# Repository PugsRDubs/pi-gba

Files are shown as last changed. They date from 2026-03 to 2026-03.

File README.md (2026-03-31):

# pi-gba
A simple, easy to assemble, DIY retro gaming handheld.

The pi-gba was designed to be pretty easy to build. Order the pcb, parts, and 3d print the case, and assembly is straightforward. The pi, battery board, and usbc breakout are placed on top of and soldered directly to the main board.

### images
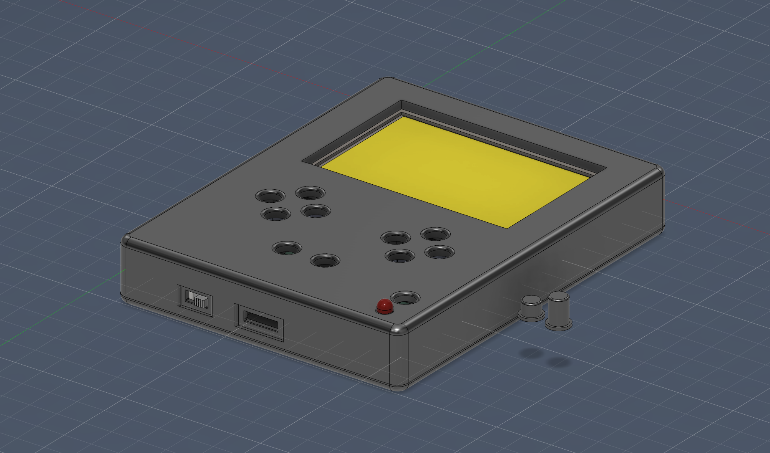
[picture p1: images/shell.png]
Shell

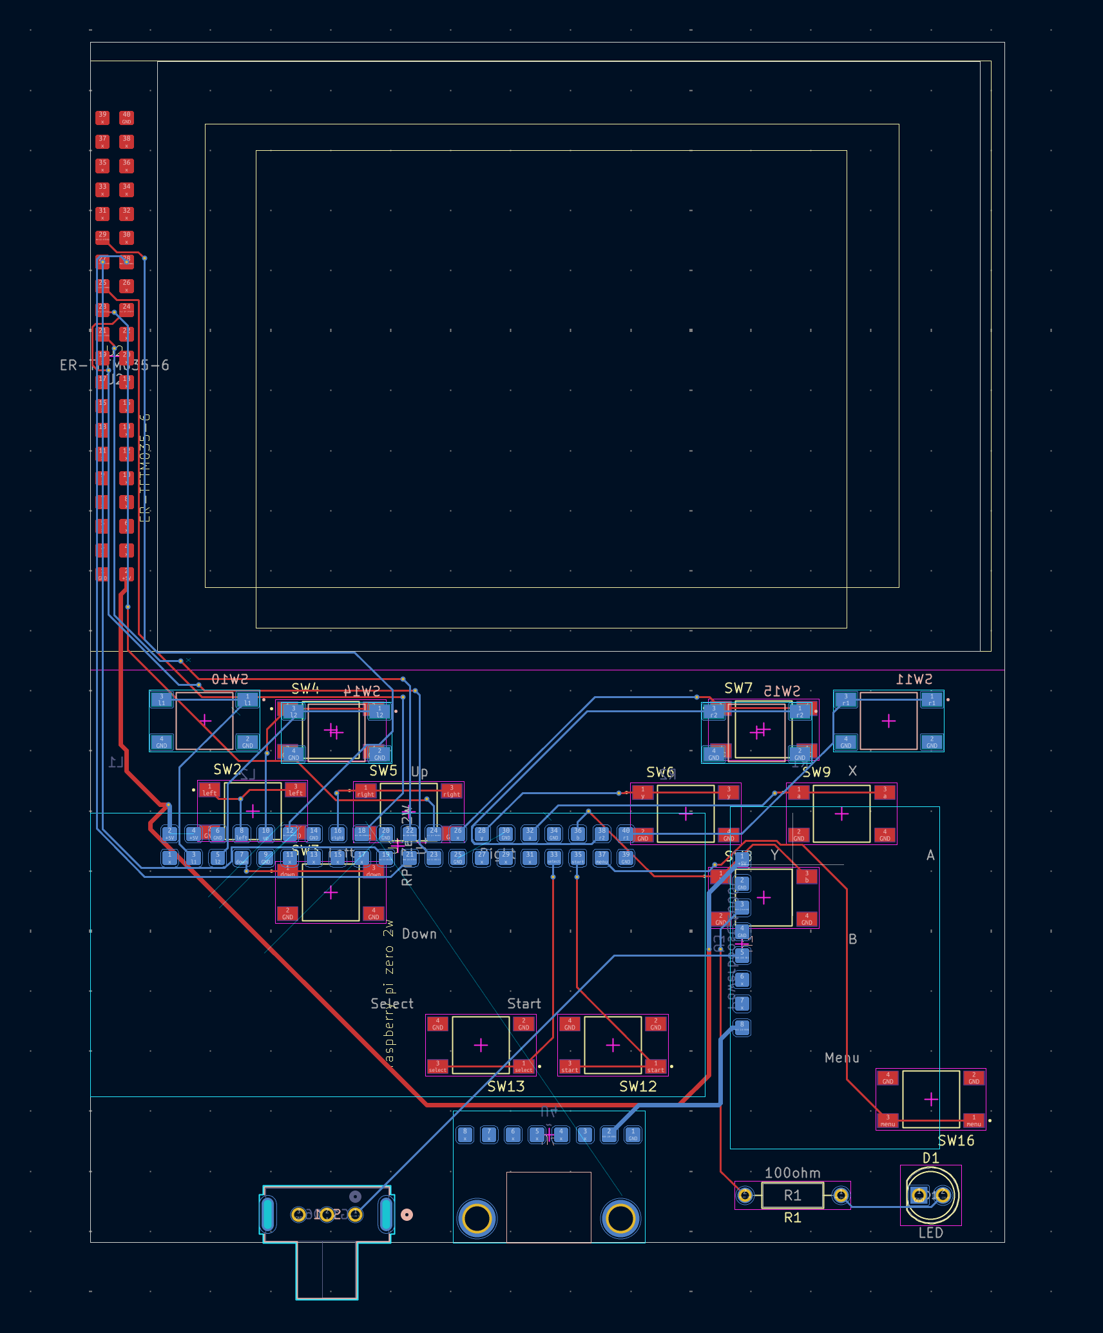
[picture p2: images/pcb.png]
PCB


### software
Flash the latest image of [retropie](https://retropie.org.uk/download/) using the raspberry pi imager. Make sure SSH is enabled and ssh into the pi from another computer (instructions [here](https://retropie.org.uk/docs/SSH/)). 
I recommend installing the [fbcp-ili9341](https://github.com/juj/fbcp-ili9341) driver, clone the git repository and follow the instructions to build from source make sure to pass the flag `-DILI9488=ON` when compiling, as that is the driver that this project's screen uses. 
For keyboard controls I would use [retrogame](https://github.com/adafruit/Adafruit-Retrogame/tree/master), follow their instructions for install and then you should be able to use the `retrogame.cfg` from this repository.
Note this software has not been tested yet with this project.

| Item | Qty. | Price(USD) | Link |
|---|---|---|---|
| ER-TFTM035-6 | 1 | 13.43 | https://www.buydisplay.com/lcd-3-5-inch-320x480-tft-display-module-optl-touch-screen-w-breakout-board |
| BuyDisplay shipping | 1 | 9.41 | N/A |
| PowerBoost 1000 | 1 | 19.95 | https://www.digikey.com/en/products/detail/adafruit-industries-llc/2465/5356834 |
| USB-C Breakout | 1 | 2.95 | https://www.digikey.com/en/products/detail/adafruit-industries-llc/4090/9951930 |
| TS04-66-55-BK-100-SMT | 15 | 0.143 | https://www.digikey.com/en/products/detail/same-sky-formerly-cui-devices/TS04-66-55-BK-100-SMT/15634326 |
| LTL-307E | 1 | 0.14 | https://www.digikey.com/en/products/detail/liteon/LTL-307E/669997 |
| CFM14JT100R | 1 | 0.10 | https://www.digikey.com/en/products/detail/stackpole-electronics-inc/CFM14JT100R/1742057 |
| EG1206 | 1 | 0.74 | https://www.digikey.com/en/products/detail/e-switch/EG1206/251333 |
| 2500mAh battery | 1 | 14.95 | https://www.digikey.com/en/products/detail/e-switch/EG1206/251333 |
| Digikey Shipping | 1 | 4.99 | N/A |
| PCB | 1 | 9.00 | N/A |
| JLCPCB Shipping + taxes | 1 | 39.44 | N/A |
| Raspberry Pi Zero 2 W | 1 | 19.05 | https://www.adafruit.com/product/5291 |

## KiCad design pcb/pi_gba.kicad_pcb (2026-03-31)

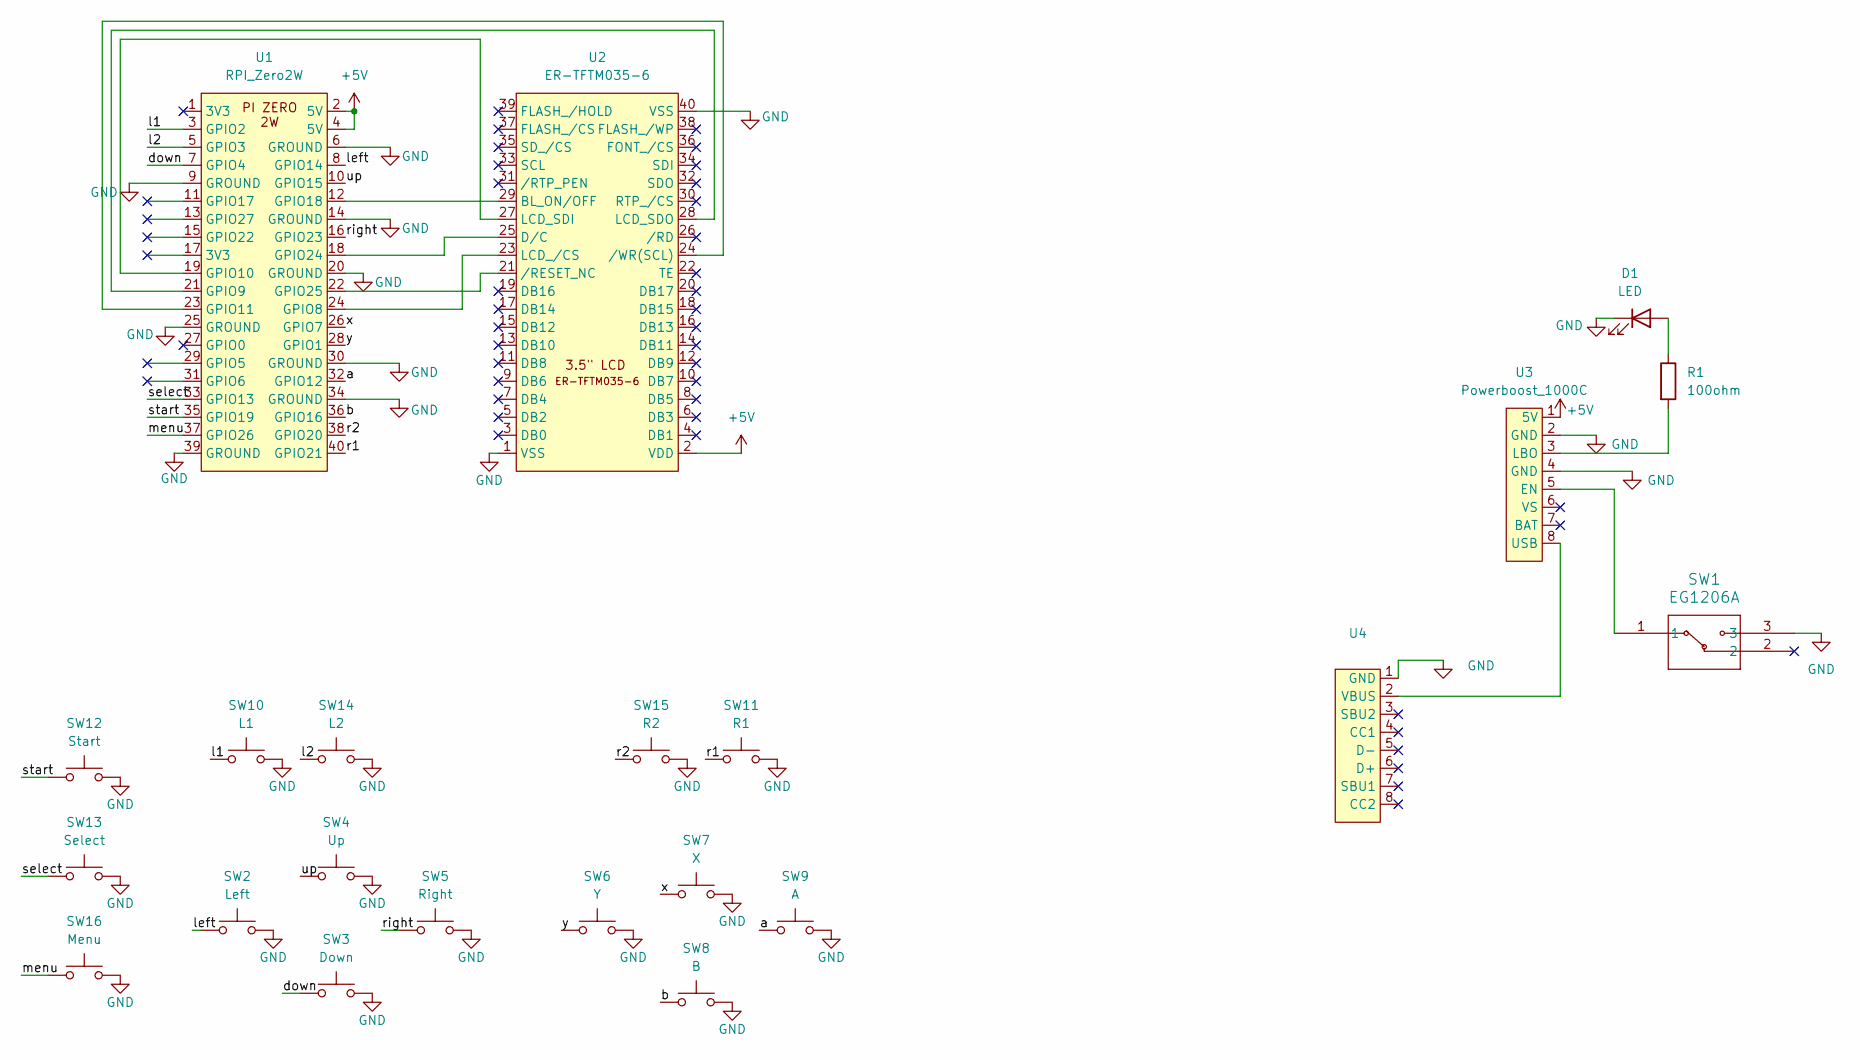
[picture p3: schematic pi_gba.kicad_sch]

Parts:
D1: LED; LED_D5.0mm
R1: 100ohm; R_Axial_DIN0207_L6.3mm_D2.5mm_P10.16mm_Horizontal
SW1: EG1206A; EG1206A_EWI
SW2: Left; SW_TS04-66-55-BK-100-SMT
SW3: Down; SW_TS04-66-55-BK-100-SMT
SW4: Up; SW_TS04-66-55-BK-100-SMT
SW5: Right; SW_TS04-66-55-BK-100-SMT
SW6: Y; SW_TS04-66-55-BK-100-SMT
SW7: X; SW_TS04-66-55-BK-100-SMT
SW8: B; SW_TS04-66-55-BK-100-SMT
SW9: A; SW_TS04-66-55-BK-100-SMT
SW10: L1; SW_TS04-66-55-BK-100-SMT
SW11: R1; SW_TS04-66-55-BK-100-SMT
SW12: Start; SW_TS04-66-55-BK-100-SMT
SW13: Select; SW_TS04-66-55-BK-100-SMT
SW14: L2; SW_TS04-66-55-BK-100-SMT
SW15: R2; SW_TS04-66-55-BK-100-SMT
SW16: Menu; SW_TS04-66-55-BK-100-SMT
U1: RPI_Zero2W; pi_zero_2w
U2: ER-TFTM035-6
U3: Powerboost_1000C; adafruit_powerboost_1000c
U4: adafruit_usbc_breakout

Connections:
+5V: U1.2 (5V), U1.4 (5V), U2.2 (VDD), U3.1 (5V)
/a: SW9.1, SW9.3 (1), U1.32 (GPIO12)
/b: SW8.1, SW8.3 (1), U1.36 (GPIO16)
/down: SW3.1, SW3.3 (1), U1.7 (GPIO4)
/l1: SW10.1, SW10.3 (1), U1.3 (GPIO2)
/l2: SW14.1, SW14.3 (1), U1.5 (GPIO3)
/left: SW2.1, SW2.3 (1), U1.8 (GPIO14)
/menu: SW16.1, SW16.3 (1), U1.37 (GPIO26)
/r1: SW11.1, SW11.3 (1), U1.40 (GPIO21)
/r2: SW15.1, SW15.3 (1), U1.38 (GPIO20)
/right: SW5.1, SW5.3 (1), U1.16 (GPIO23)
/select: SW13.1, SW13.3 (1), U1.33 (GPIO13)
/start: SW12.1, SW12.3 (1), U1.35 (GPIO19)
/up: SW4.1, SW4.3 (1), U1.10 (GPIO15)
/x: SW7.1, SW7.3 (1), U1.26 (GPIO7)
/y: SW6.1, SW6.3 (1), U1.28 (GPIO1)
GND: D1.1 (K), SW1.3, SW2.2, SW2.4 (2), SW3.2, SW3.4 (2), SW4.2, SW4.4 (2), SW5.2, SW5.4 (2), SW6.2, SW6.4 (2), SW7.2, SW7.4 (2), SW8.2, SW8.4 (2), SW9.2, SW9.4 (2), SW10.2, SW10.4 (2), SW11.2, SW11.4 (2), SW12.2, SW12.4 (2), SW13.2, SW13.4 (2), SW14.2, SW14.4 (2), SW15.2, SW15.4 (2), SW16.2, SW16.4 (2), U1.6 (GROUND), U1.9 (GROUND), U1.14 (GROUND), U1.20 (GROUND), U1.25 (GROUND), U1.30 (GROUND), U1.34 (GROUND), U1.39 (GROUND), U2.1 (VSS), U2.40 (VSS), U3.2 (GND), U3.4 (GND), U4.1 (GND)
unnamed: D1.2 (A), R1.1
unnamed: U1.24 (GPIO8), U2.23 (LCD_/CS)
unnamed: U1.21 (GPIO9), U2.28 (LCD_SDO)
unnamed: U1.19 (GPIO10), U2.27 (LCD_SDI)
unnamed: U1.23 (GPIO11), U2.24 (/WR(SCL))
unnamed: U1.12 (GPIO18), U2.29 (BL_ON/OFF)
unnamed: U1.18 (GPIO24), U2.25 (D/C)
unnamed: U1.22 (GPIO25), U2.21 (/RESET_NC)
unnamed: SW1.1, U3.5 (EN)
unnamed: R1.2, U3.3 (LBO)
unnamed: U3.8 (USB), U4.2 (VBUS)

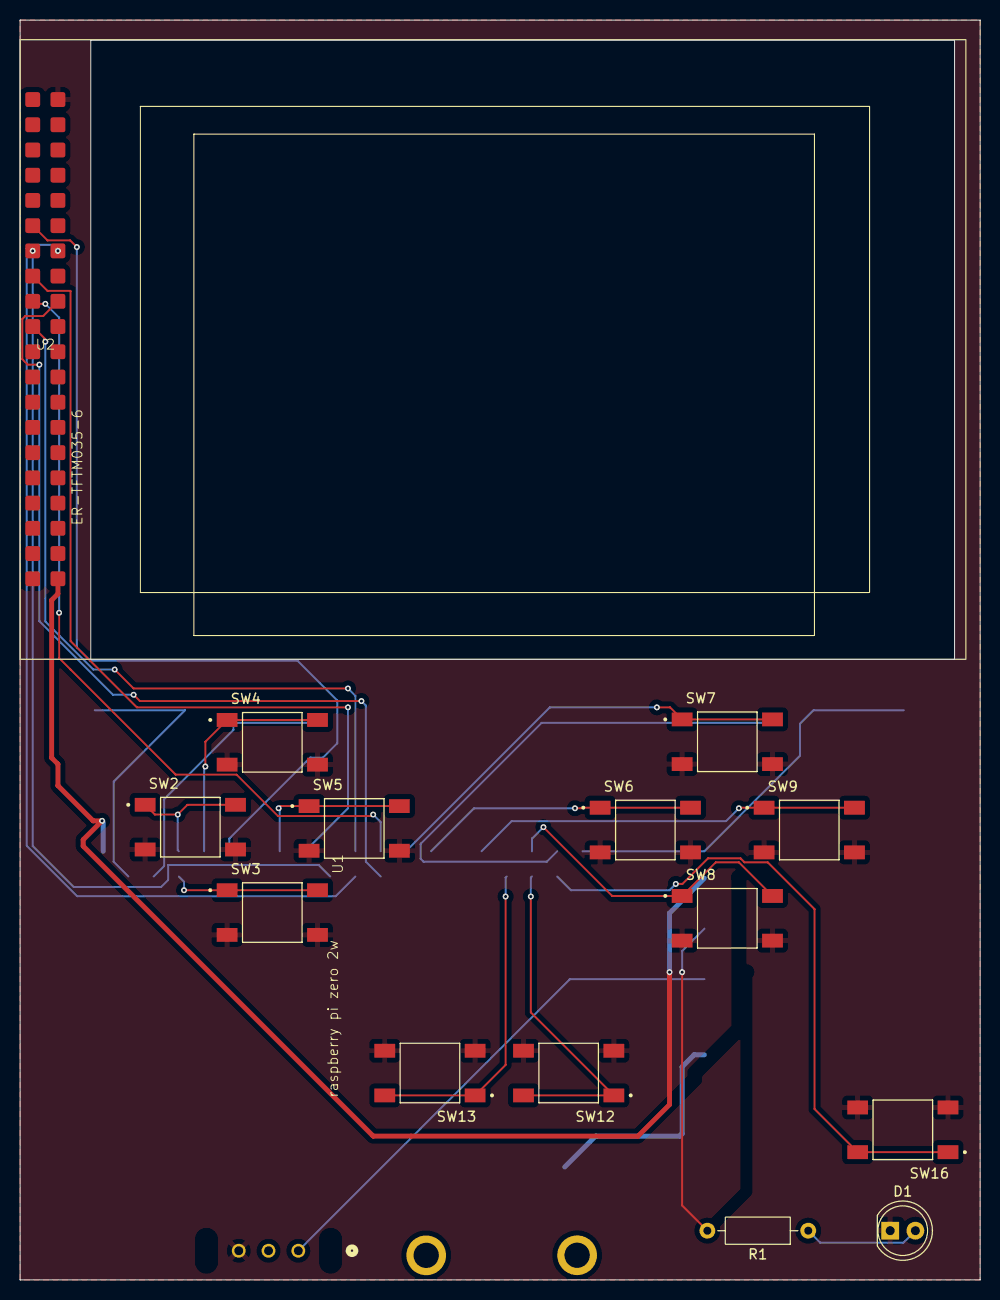
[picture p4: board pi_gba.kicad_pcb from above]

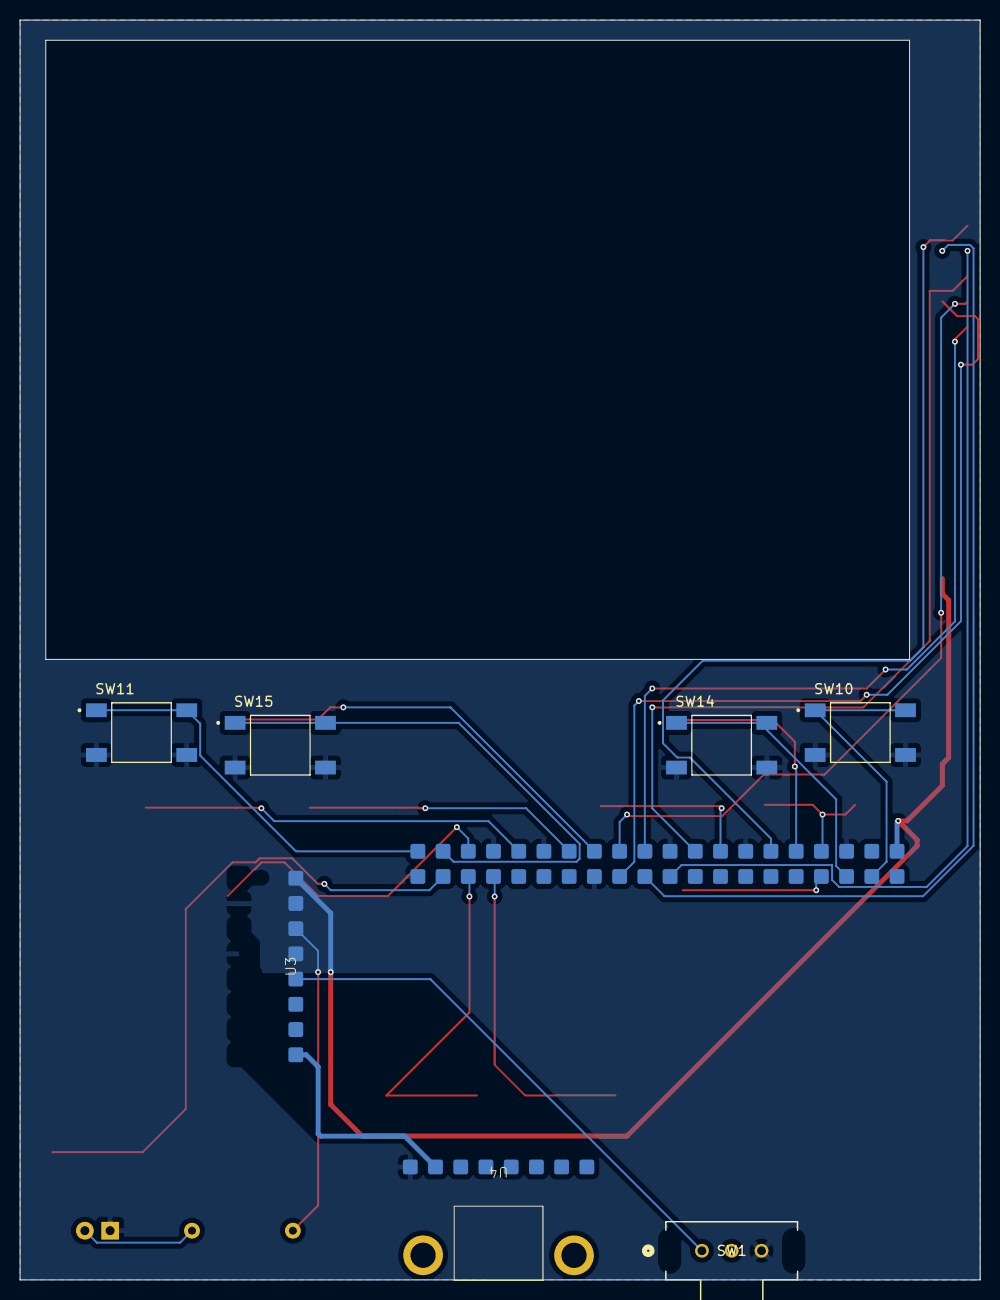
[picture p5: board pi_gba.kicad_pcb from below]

Board: 2 copper layers, 96.7 x 126.9 mm, 22 parts (7 on the bottom side), 28 nets.

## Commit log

2026-03-31 add project files
    [BOM.csv, pi_gba.kicad_pcb, pi_gba.kicad_sch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]
2026-03-31 change button
2026-05-04 schematic redesign
    [pi_gba.kicad_sch]
